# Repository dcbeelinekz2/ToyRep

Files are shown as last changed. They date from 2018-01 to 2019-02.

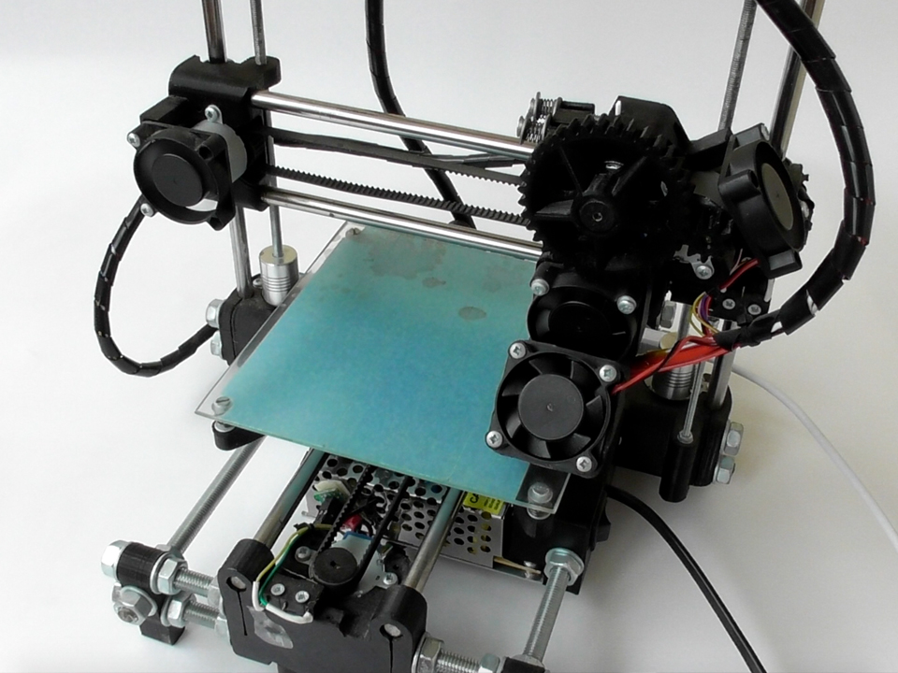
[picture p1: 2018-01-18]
Foto.jpg

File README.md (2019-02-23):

# Маленький и дешевый 3D-принтер ToyRep
Собираем дешевый 3D принтер. Стоимость минимальна, способен печатать PLA пластиком небольшие детали.

Сайт проекта: http://reprap.org/wiki/ToyREP

Инструкция по сборке: http://reprap.org/wiki/ToyREP_Build_Manual

#### Контроллер
Arduino Mega 2560 R3 + RAMPS 1.4

#### Youtube Видео
ToyRep (http://www.youtube.com/watch?v=H17Mea6-Euc)

#### Ссылки на сопутствующие товары:
* https://goo.gl/ScGgkq Arduino Mega 2560 R3 + RAMPS 1.4;
* https://goo.gl/J6td6x 12В 40Вт E3D экструдер;
* https://goo.gl/RAEKTG Вентиляторы;
* https://goo.gl/mcKLWA Блок питания;
* https://goo.gl/QV5YUb Подогреваемый стол;
* https://goo.gl/QgaRqG Подшипник LM8UU;
* https://goo.gl/iuyrqx Подшипник 608ZZ;
* https://goo.gl/V6uqep Подшипник 624ZZ;
* https://goo.gl/EZKZaS Болт экструдера;
* https://goo.gl/Zm23vD Ремень;

Группа в VK: http://vk.com/WhatWouldSolder. Что бы Такого Спаять?

По всем вопросам: info@phpscript.ru

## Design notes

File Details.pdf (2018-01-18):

# ToyRep (RepRap) 125x125

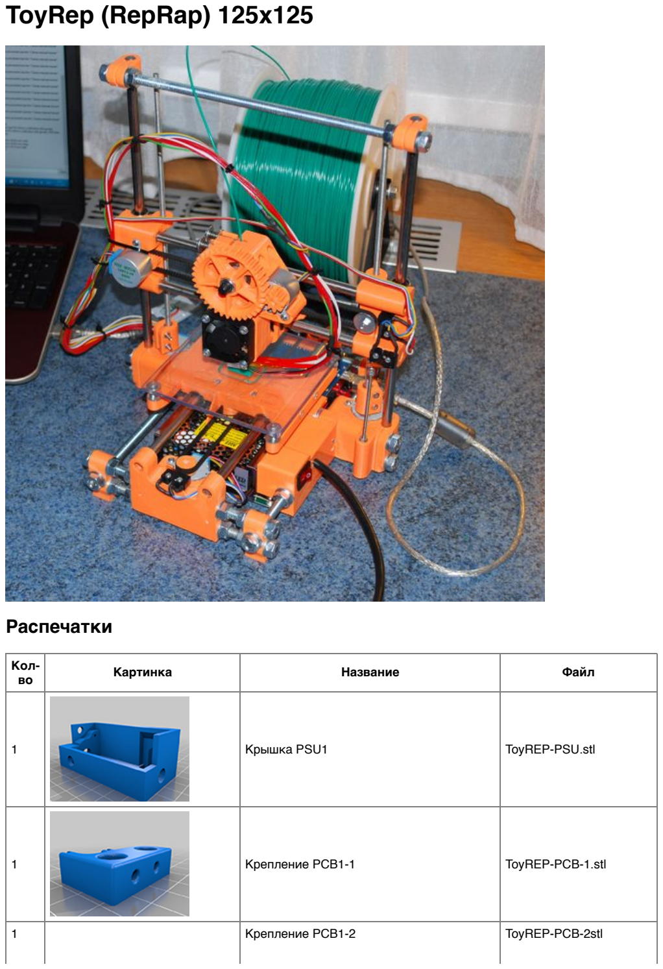
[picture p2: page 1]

## Распечатки

Кол-во | Картинка | Название | Файл
1 | | Крышка PSU1 | ToyREP-PSU.stl
1 | | Крепление PCB1-1 | ToyREP-PCB-1.stl
1 | Крепление PCB1-2 | ToyREP-PCB-2stl

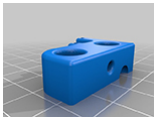
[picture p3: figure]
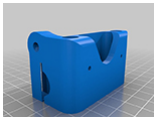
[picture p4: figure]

1 | Левая ось X | ToyREP-X1.stl

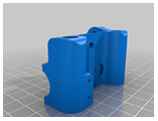
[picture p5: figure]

1 | Правая ось X | ToyREP-X2.stl

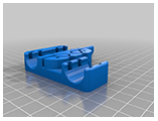
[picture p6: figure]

1 | Каретка | ToyREP-Carriage.stl

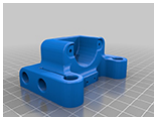
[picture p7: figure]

1 | Переднее крепление мотора оси Y | ToyREP-Y1.stl

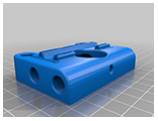
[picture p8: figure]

1 | Заднее крепление пошшипника оси Y | ToyREP-Y2.stl
1 | База стола | ToyREP-Frog.stl

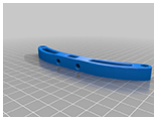
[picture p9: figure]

2 | Крепление 125 мм стола | ToyREP-Frog125.stl
4 | Ножка | ToyREP-Leg.stl

1 | Левое крепление Z мотора | ToyREP-Z1.stl
1 | Правое крепление Z мотора | ToyREP-Z2.stl
1 | Верхнее крепление оси Z | ToyREP-ZMAX1.stl

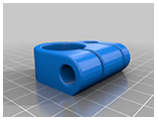
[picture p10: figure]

1 | Верхнее крепление оси Z | ToyREP-ZMAX2.stl
2 | Шкив под ремень T2.5 | ToyREP-T2.5_Pulley.stl
2 | Переходник Z мотора | ToyREP-Z_Joint.stl
1 | Корпус экструдера | ToyREP-Extruder.stl
1 | Натяжитель экструдера | ToyREP-Idler.stl

1 | Шестеренка 36 зубов | ToyREP-Gear.stl

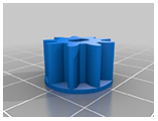
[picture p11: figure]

1 | Шестеренка 9 зубов | ToyREP-Pinion.stl
1 | Крепление вентилятора хотэнда | ToyREP-Fan.stl
1 | Обдув пластика | ToyREP-Cooler.stl

## Железки

Кол-во | Картинка | Название | Купить
3 | | Шпилька M8 x 265мм
2 | | Шпилька M8 x 265мм

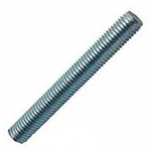
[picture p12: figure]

4 | Шпилька M8 x 180мм
2 | Шпилька M5 x 250мм (движение по Z)
1 | Шпилька M3 x 105мм (концевик Z)
2 | Полированный вал Y оси Ø8 x 245мм
2 | Полированный вал Z оси Ø8 x 295мм

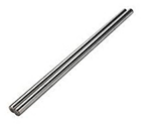
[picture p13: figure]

2 | Полированный вал X оси Ø8 x 255мм
1 | Полированный вал Ø8 x 15мм (шкив натяжителя экструдера)

6 | Гайка M5 (Z axis movement. Glue them to into X1 and X2 plastic part)

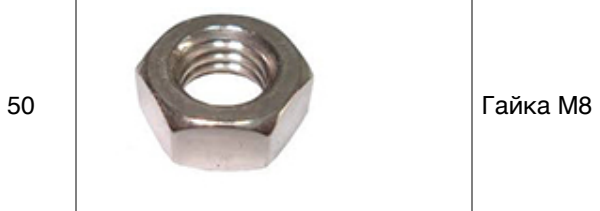
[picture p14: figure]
Гайка M8

4 | Стойка для печатных плат M3 x 12мм
6 | Гайка самоконтрящаяся M3 (для базы и экструдера)
1 | Гайка самоконтрящаяся M8 (для болта экструдера)

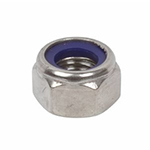
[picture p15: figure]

84 | Шайба M8 (для подгона размеров. кол-во может отличаться)

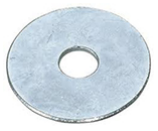
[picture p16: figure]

2 | Шайба кузовная M6 (на подшипники 624ZZ)
4 | Винт с полукруглой головкой M3 x 16мм (жля вентиляторов)

4 | Винт с полукруглой головкой M3 x 35мм (для каретки)
2 | Винт с полукруглой головкой M4 x 20мм (для подшипников 624ZZ)
3 | Винт с потайной головкой M3 X 10мм (для БП)

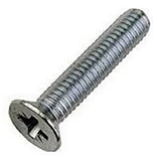
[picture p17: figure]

4 | Винт с потайной головкой M3 x 20мм (для Z)
5 | Винт с потайной головкой M3 x 25мм (для стола и натяжителя)
2 | Винт с потайной головкой M3 x 30мм (для hotend)
6 | Винт с потайной головкой M4 x 50мм (для крепления стола и мотора экструдера)

6 | Шуруп с полукруглой головкой 2.5 X 10мм (для X, Y, Z концевиков)

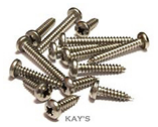
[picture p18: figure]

11 | Шуруп с полукруглой головкой M3 X 13мм (для БП и моторов)
6 | Шуруп с полукруглой головкой M3 X 20-25мм (для вентиляторов)
11 | LM8UU подшипник (можно заменить на напечатанный вариант)

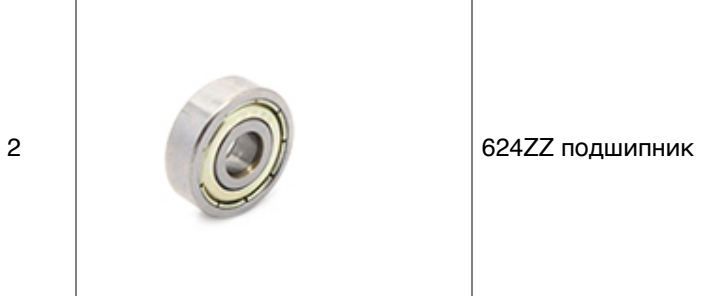
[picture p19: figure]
624ZZ подшипник

1 | M8 болт экструдера (Hyena hobbed bolt)

6 | Ø7 / 5 x 15мм пружины (для экструдера и стола)

Механика / Электроника

Кол-во | Картинка | Название | Купить

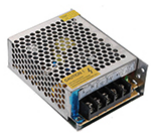
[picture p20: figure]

1 | | Блок питания 12В 40Вт (111 x 78 x 36мм)
1 | | Arduino Mega 2560 R3

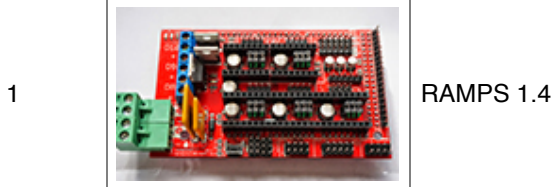
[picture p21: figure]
RAMPS 1.4

2 | Кмемма с шагом 5мм

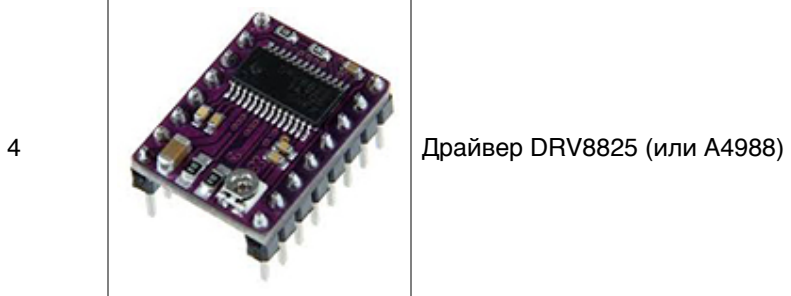
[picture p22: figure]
Драйвер DRV8825 (или A4988)

5 | 5В 28BYJ-48 мотор (с проводами 850, 500, 250, 180 и 120мм)
3 | Микро-выключатель (с проводами 850, 850 and 300мм)
1 | 12В 40Вт E3D экструдер (с проводом 950мм и резистором 100k)

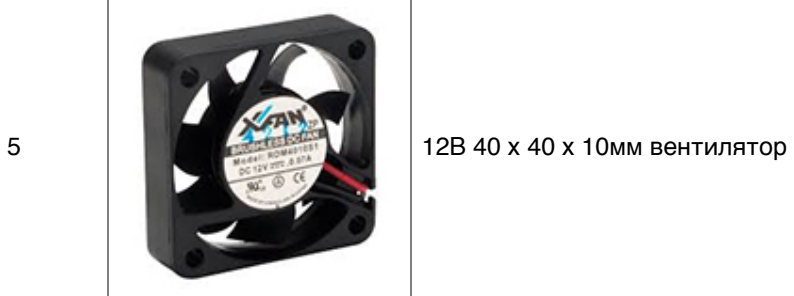
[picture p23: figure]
12В 40 x 40 x 10мм вентилятор

1 | Кабель питания

1 | 200мм провода
1 | Включатель 13x19мм (250В, 1A)

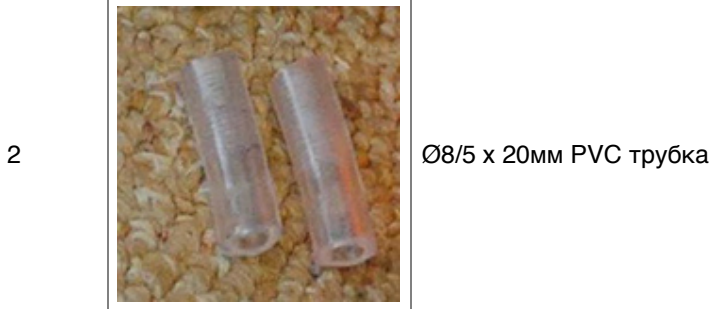
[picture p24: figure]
Ø8/5 x 20мм PVC трубка
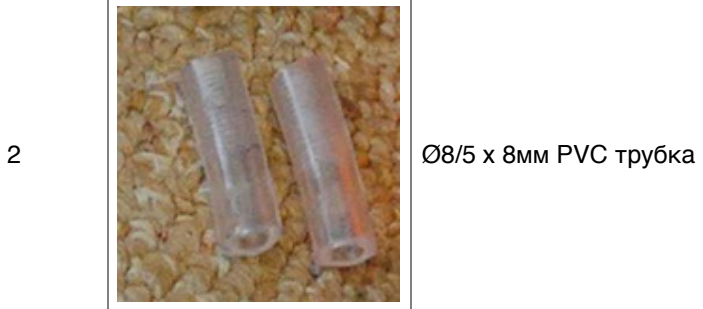
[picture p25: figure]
Ø8/5 x 8мм PVC трубка

1 | 145 x 145 x 3мм оргстекло (отверстия 130 x 130мм)
33 | Стяжки

Провода

Оплетка проводов

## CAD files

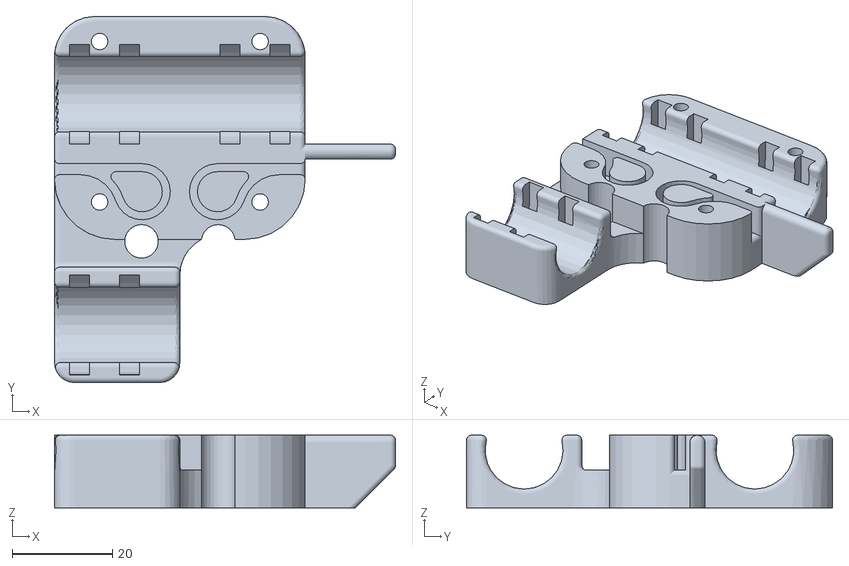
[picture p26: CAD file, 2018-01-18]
3D print/ToyREP-Carriage.stl
68.0 x 73.0 x 14.5

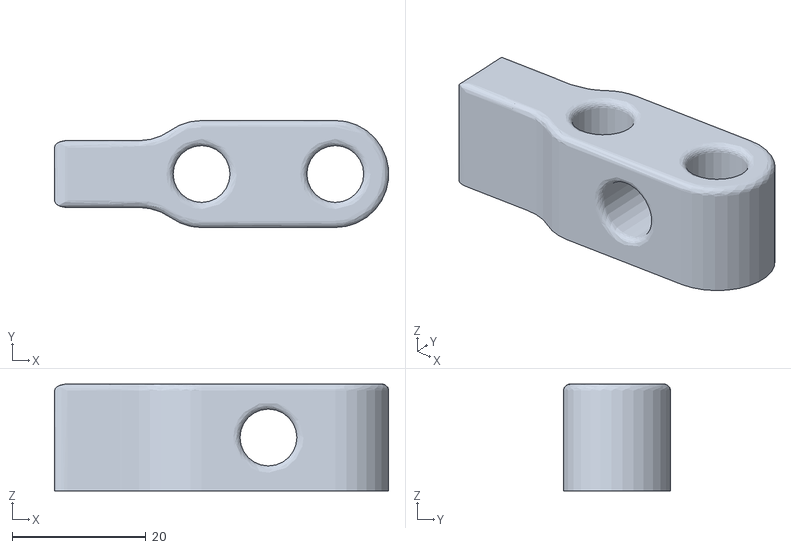
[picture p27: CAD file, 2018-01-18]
3D print/ToyREP-Leg.stl
50.0 x 16.0 x 16.0

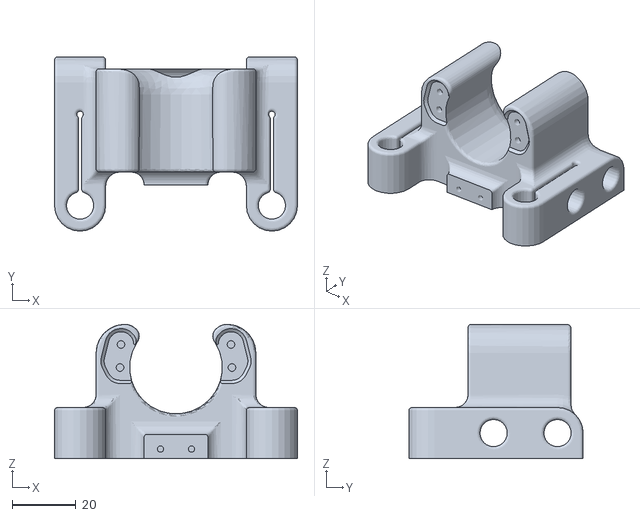
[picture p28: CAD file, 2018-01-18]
3D print/ToyREP-Y1.stl
76.0 x 54.5 x 42.0

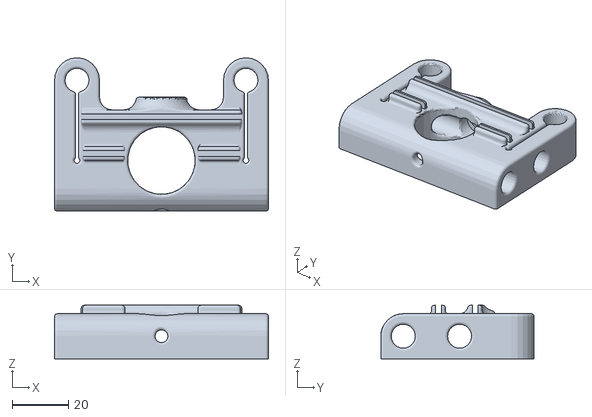
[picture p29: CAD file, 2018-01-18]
3D print/ToyREP-Y2.stl
76.0 x 54.5 x 19.0

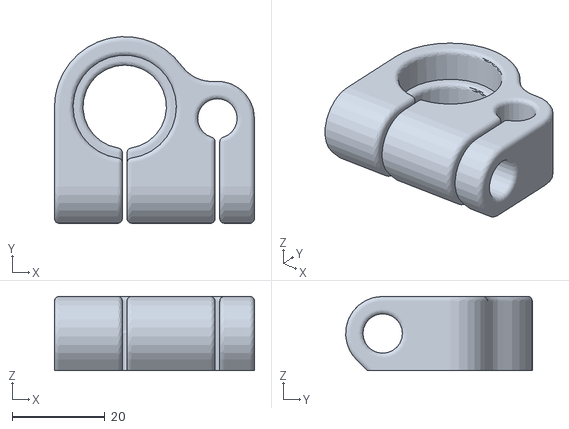
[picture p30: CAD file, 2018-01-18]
3D print/ToyREP-ZMAX2.stl
43.1 x 40.2 x 16.0

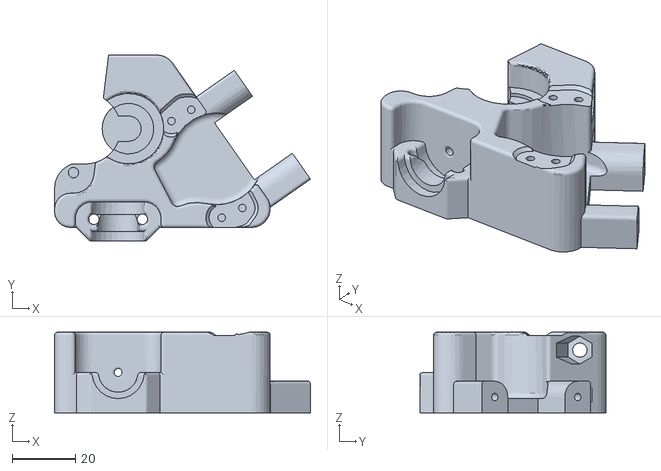
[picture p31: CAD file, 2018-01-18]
3D print/ToyREP-Extruder.stl
80.9 x 58.8 x 25.5

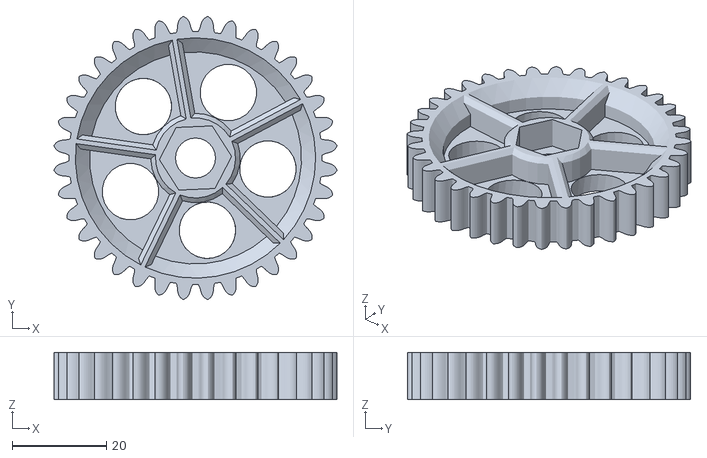
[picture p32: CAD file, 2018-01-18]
3D print/ToyREP-Gear.stl
60.1 x 60.1 x 10.00

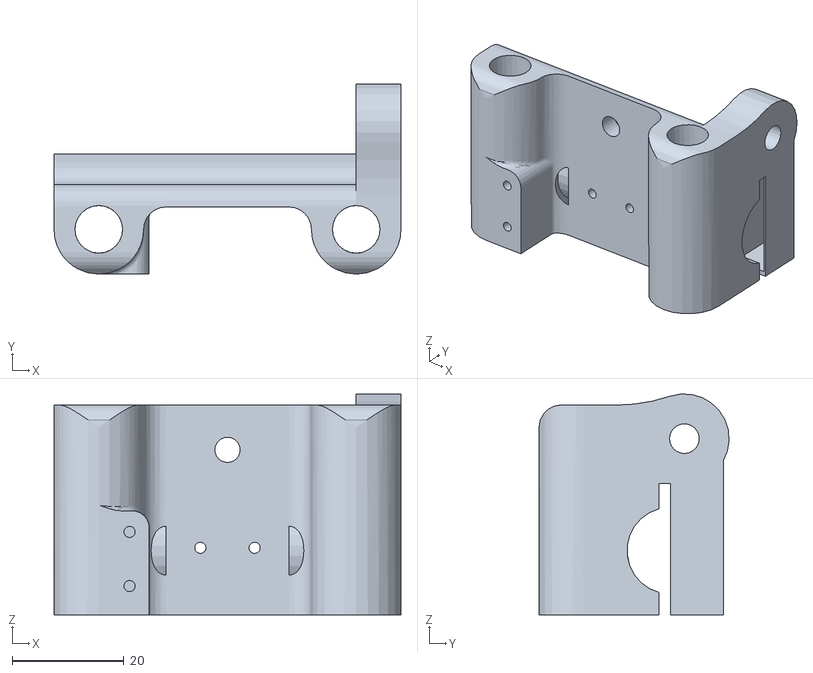
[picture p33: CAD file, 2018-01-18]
3D print/ToyREP-X2.stl
62.0 x 34.0 x 39.5

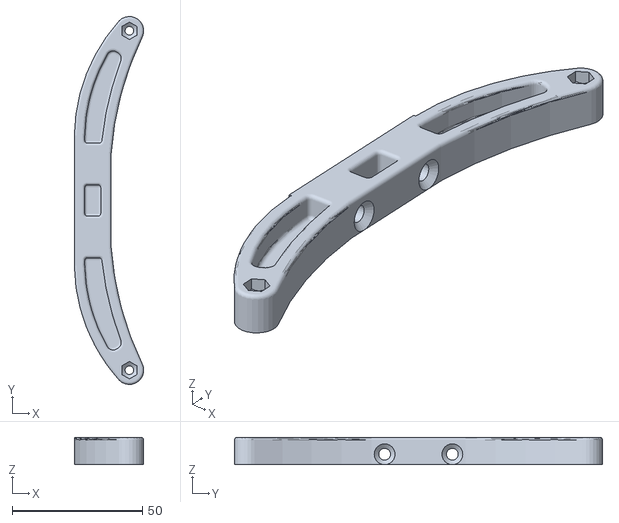
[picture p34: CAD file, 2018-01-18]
3D print/ToyREP-Frog125.stl
26.6 x 141.3 x 10.5

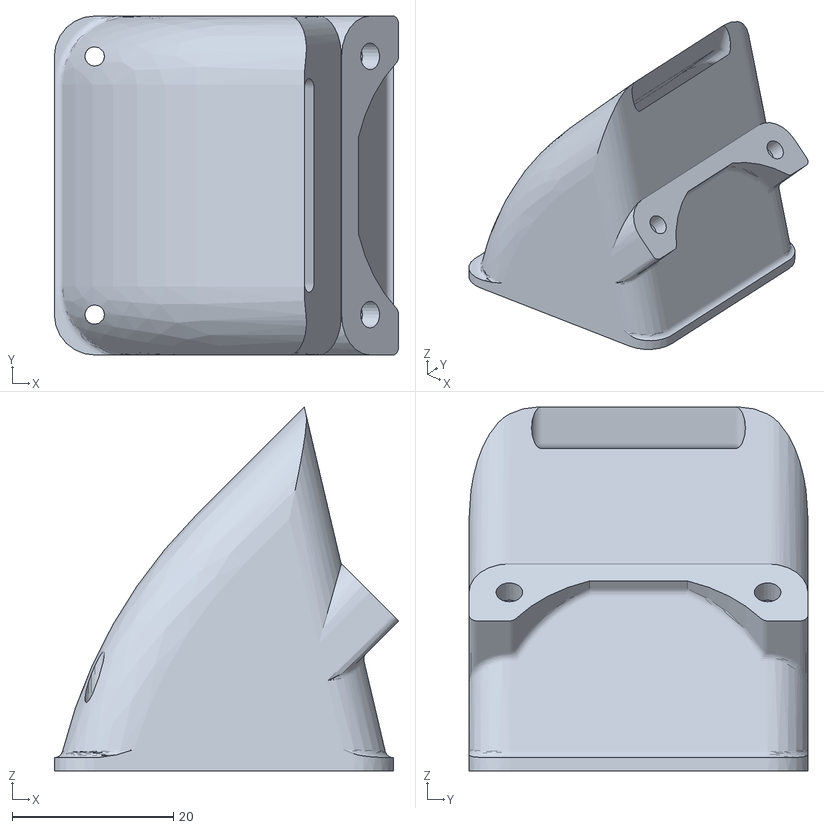
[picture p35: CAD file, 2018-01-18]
3D print/ToyREP-Cooler.stl
42.7 x 42.0 x 45.1

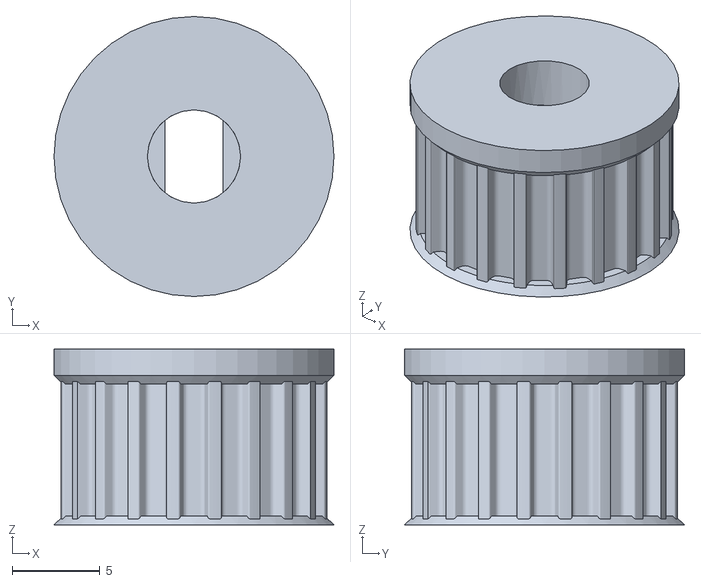
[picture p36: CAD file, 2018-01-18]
3D print/ToyREP-T2.5_Pulley.stl
15.9 x 15.9 x 10.00

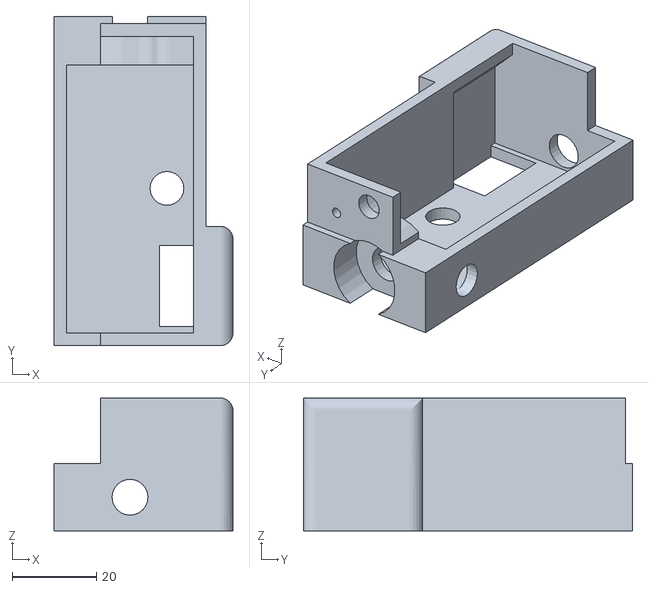
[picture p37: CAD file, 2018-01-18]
3D print/ToyREP-PSU.stl
42.4 x 78.0 x 31.5

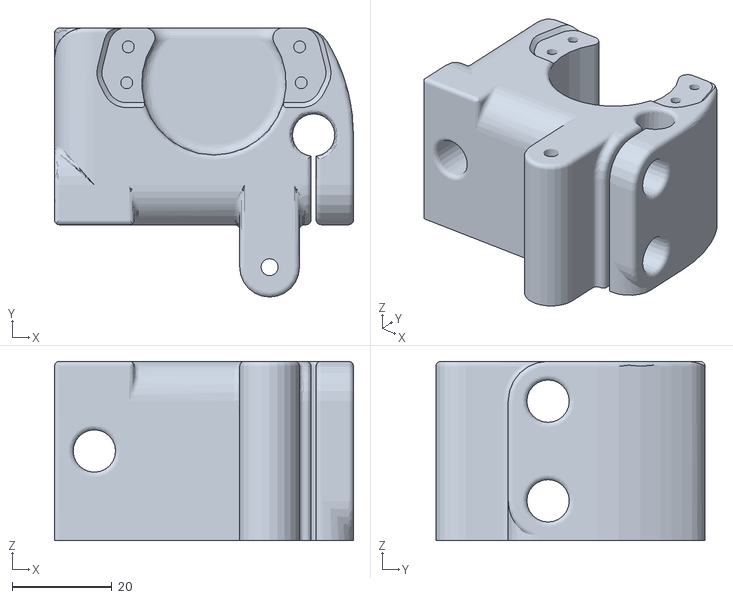
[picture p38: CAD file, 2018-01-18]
3D print/ToyREP-Z2.stl
60.0 x 54.0 x 36.0

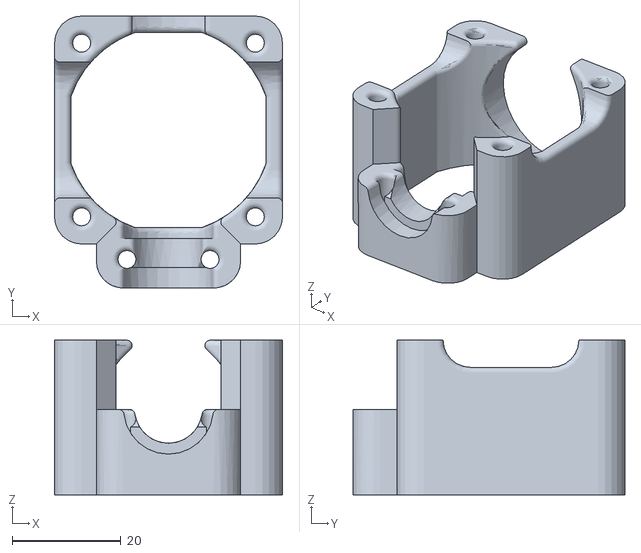
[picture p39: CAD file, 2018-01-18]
3D print/ToyREP-Fan.stl
42.0 x 50.1 x 28.5

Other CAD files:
3D print/ToyREP-ZMAX1.stl
3D print/ToyREP-Z_Joint.stl
3D print/ToyREP-Z1.stl
3D print/ToyREP-Frog.stl
3D print/ToyREP-Idler.stl
3D print/ToyREP-PCB-1.stl
3D print/ToyREP-PCB-2.stl
3D print/ToyREP-Pinion.stl
3D print/ToyREP-X1.stl

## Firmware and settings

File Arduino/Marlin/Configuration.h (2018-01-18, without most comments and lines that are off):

#define CONFIGURATION_H
#define STRING_VERSION_CONFIG_H __DATE__ " " __TIME__ // build date and time
#define STRING_CONFIG_H_AUTHOR "(thorgal, ToyREP)" // Who made the changes.
#define SERIAL_PORT 0
#define BAUDRATE 250000
#define MOTHERBOARD 33
#define CUSTOM_MENDEL_NAME "ToyREP"
#define EXTRUDERS 1
#define POWER_SUPPLY 1
#define TEMP_SENSOR_0 1
#define TEMP_SENSOR_1 0
#define TEMP_SENSOR_2 0
#define TEMP_SENSOR_BED 0
#define MAX_REDUNDANT_TEMP_SENSOR_DIFF 10
#define TEMP_RESIDENCY_TIME 5  // (seconds)
#define TEMP_HYSTERESIS 3       // (degC) range of +/- temperatures considered "close" to the target one
#define TEMP_WINDOW     1       // (degC) Window around target to start the residency timer x degC early.
#define HEATER_0_MINTEMP 5
#define HEATER_1_MINTEMP 5
#define HEATER_2_MINTEMP 5
#define BED_MINTEMP 5
#define HEATER_0_MAXTEMP 275
#define HEATER_1_MAXTEMP 275
#define HEATER_2_MAXTEMP 275
#define BED_MAXTEMP 150
#define EXTRUDER_WATTS (12.0*12.0/3.6) //  P=I^2/R
#define PIDTEMP //run autotune M303 S185 to get the correct values
#define BANG_MAX 255 // limits current to nozzle while in bang-bang mode; 255=full current
#define PID_MAX 255 // limits current to nozzle while PID is active (see PID_FUNCTIONAL_RANGE below); 255=full current
  #define PID_FUNCTIONAL_RANGE 100 // If the temperature difference between the target temperature and the actual temperature
  #define PID_INTEGRAL_DRIVE_MAX 255  //limit for the integral term
  #define K1 0.95 //smoothing factor within the PID
  #define PID_dT ((OVERSAMPLENR * 10.0)/(F_CPU / 64.0 / 256.0)) //sampling period of the temperature routine
    #define  DEFAULT_Kp 16.51
    #define  DEFAULT_Ki 0.87
    #define  DEFAULT_Kd 78.47
#define MAX_BED_POWER 255 // limits duty cycle to bed; 255=full current
#define PREVENT_DANGEROUS_EXTRUDE
#define PREVENT_LENGTHY_EXTRUDE
#define EXTRUDE_MINTEMP 170
#define EXTRUDE_MAXLENGTH (X_MAX_LENGTH+Y_MAX_LENGTH) //prevent extrusion of very large distances.
#define ENDSTOPPULLUPS // Comment this out (using // at the start of the line) to disable the endstop pullup resistors
  #define ENDSTOPPULLUP_XMAX
  #define ENDSTOPPULLUP_YMAX
  #define ENDSTOPPULLUP_ZMIN
const bool X_MIN_ENDSTOP_INVERTING = false; // set to true to invert the logic of the endstop.
const bool Y_MIN_ENDSTOP_INVERTING = false; // set to true to invert the logic of the endstop.
const bool Z_MIN_ENDSTOP_INVERTING = false; // set to true to invert the logic of the endstop.
const bool X_MAX_ENDSTOP_INVERTING = false; // set to true to invert the logic of the endstop.
const bool Y_MAX_ENDSTOP_INVERTING = false; // set to true to invert the logic of the endstop.
const bool Z_MAX_ENDSTOP_INVERTING = false; // set to true to invert the logic of the endstop.
#if defined(COREXY) && !defined(DISABLE_MAX_ENDSTOPS)
  #define DISABLE_MAX_ENDSTOPS
#endif
#define X_ENABLE_ON 0
#define Y_ENABLE_ON 0
#define Z_ENABLE_ON 0
#define E_ENABLE_ON 0 // For all extruders
#define DISABLE_X true
#define DISABLE_Y true
#define DISABLE_Z true
#define DISABLE_E true // For all extruders
#define DISABLE_INACTIVE_EXTRUDER true //disable only inactive extruders and keep active extruder enabled
#define INVERT_X_DIR true    // for Mendel set to false, for Orca set to true
#define INVERT_Y_DIR false    // for Mendel set to true, for Orca set to false
#define INVERT_Z_DIR true     // for Mendel set to false, for Orca set to true
#define INVERT_E0_DIR true   // for direct drive extruder v9 set to true, for geared extruder set to false
#define INVERT_E1_DIR false    // for direct drive extruder v9 set to true, for geared extruder set to false
#define INVERT_E2_DIR false   // for direct drive extruder v9 set to true, for geared extruder set to false
#define X_HOME_DIR 1
#define Y_HOME_DIR 1
#define Z_HOME_DIR -1
#define min_software_endstops false // If true, axis won't move to coordinates less than HOME_POS.
#define max_software_endstops false // If true, axis won't move to coordinates greater than the defined lengths below.
#define X_MAX_POS 133
#define X_MIN_POS 8
#define Y_MAX_POS 126
#define Y_MIN_POS 1
#define Z_MAX_POS 125
#define Z_MIN_POS 0
#define X_MAX_LENGTH (X_MAX_POS - X_MIN_POS)
#define Y_MAX_LENGTH (Y_MAX_POS - Y_MIN_POS)
#define Z_MAX_LENGTH (Z_MAX_POS - Z_MIN_POS)
#define Z_PROBE_REPEATABILITY_TEST  // If not commented out, Z-Probe Repeatability test will be included if Auto Bed Leveling is Enabled.
#define MANUAL_HOME_POSITIONS  // If defined, MANUAL_*_HOME_POS below will be used
#define MANUAL_X_HOME_POS 133
#define MANUAL_Y_HOME_POS 126
#define MANUAL_Z_HOME_POS 0
#define NUM_AXIS 4 // The axis order in all axis related arrays is X, Y, Z, E
#define HOMING_FEEDRATE {600, 600, 18, 0}  // set the homing speeds (mm/min)
#define DEFAULT_AXIS_STEPS_PER_UNIT   {655.36, 655.36, 40960, 6953.59}  // calculation (32*63.68395*16)/50, (32*63.68395*16)/50, (32*63.68395*8)/0.8, (32*63.68395*16*36)/(9*7*3.1415926)
#define DEFAULT_MAX_FEEDRATE          {30, 30, 0.35, 4.17}    // (mm/sec)
#define DEFAULT_MAX_ACCELERATION      {500, 500, 5, 150}    // X, Y, Z, E maximum start speed for accelerated moves. E default values are good for Skeinforge 40+, for older versions raise them a lot.
#define DEFAULT_ACCELERATION          250    // X, Y, Z and E max acceleration in mm/s^2 for printing moves
#define DEFAULT_RETRACT_ACCELERATION  150   // X, Y, Z and E max acceleration in mm/s^2 for retracts
#define DEFAULT_XYJERK                0.5    // (mm/sec)
#define DEFAULT_ZJERK                 0.01     // (mm/sec)
#define DEFAULT_EJERK                 0.1    // (mm/sec)
#define CUSTOM_M_CODES
  #define CUSTOM_M_CODE_SET_Z_PROBE_OFFSET 851
  #define Z_PROBE_OFFSET_RANGE_MIN -15
  #define Z_PROBE_OFFSET_RANGE_MAX -5
#define PLA_PREHEAT_HOTEND_TEMP 180
#define PLA_PREHEAT_HPB_TEMP 70
#define PLA_PREHEAT_FAN_SPEED 255   // Insert Value between 0 and 255
#define ABS_PREHEAT_HOTEND_TEMP 240
#define ABS_PREHEAT_HPB_TEMP 100
#define ABS_PREHEAT_FAN_SPEED 255   // Insert Value between 0 and 255
#define FAN_SOFT_PWM
#define SOFT_PWM_SCALE 0
#define FILAMENT_SENSOR_EXTRUDER_NUM	0  //The number of the extruder that has the filament sensor (0,1,2)
#define MEASUREMENT_DELAY_CM			14  //measurement delay in cm.  This is the distance from filament sensor to middle of barrel
#define DEFAULT_NOMINAL_FILAMENT_DIA  3.0  //Enter the diameter (in mm) of the filament generally used (3.0 mm or 1.75 mm) - this is then used in the slicer software.  Used for sensor reading validation
#define MEASURED_UPPER_LIMIT          3.30  //upper limit factor used for sensor reading validation in mm
#define MEASURED_LOWER_LIMIT          1.90  //lower limit factor for sensor reading validation in mm
#define MAX_MEASUREMENT_DELAY			20  //delay buffer size in bytes (1 byte = 1cm)- limits maximum measurement delay allowable (must be larger than MEASUREMENT_DELAY_CM  and lower number saves RAM)
#define DEFAULT_MEASURED_FILAMENT_DIA  DEFAULT_NOMINAL_FILAMENT_DIA  //set measured to nominal initially
#include "Configuration_adv.h"
#include "thermistortables.h"

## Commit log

2017-07-12 Добавил .gitignore
2018-01-18 Начальное размещение материалов
    [Configuration.h, Configuration_adv.h, ToyREP-Carriage.stl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]
2018-01-30 Правка README.md
2019-02-23 Изменен README.md
